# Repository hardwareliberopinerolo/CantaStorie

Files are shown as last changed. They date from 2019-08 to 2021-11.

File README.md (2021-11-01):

# Canta Storie realizzato con Arduino Mini Pro a 3.3V

Il Canta Storie riproduce brani MP3 (come le storie per i bambini) al passagio di Tag RFID

Le storie, in formato MP3, sono salvate su una SD Card e riprodotte dal lettore MP3 DFPlayer

I Tag RFID possono essere riciclati per esempio usando i biglietti usati dei mezzi pubblici che utilizzano questa tecnoligia

Arduino Mini Pro a 3.3V si occupa di gestire la lettura dei Tag RFID ed eseguire i brani MP3

Nella cartella [Arduino Sketches](/00_Arduino_Sketches) sono presenti gli Sketches da caricare su Arduino

Il Canta Storie è in grado di associare in modo automatico i Tag RFID ai brani MP3 che si vogliono riprodurre attraverso l'uso di un Tag RFID Master

**Materiale necessario**
- Arduino Mini Pro a 3.3V
- MP3 DFPlayer
- SD Card con file MP3
- Lettore RFID RC522
- Tessere/Tag RFID

Nella cartella [PCB Kicad](/01_PCB_Kicad) sono presenti gli schemi elettrici per costruire il circuito e il PCB

**Altre Versioni**

[Versione con Arduino Nano e RC522](/10_Other_Versions/Arduino_Nano_RC522): E' una versione che permette di usare Arduino Nano, in modo simile al progetto [TonUINO](https://github.com/seisfeld/TonUINO)

[Versione con Arduino Nano e PN532](/10_Other_Versions)

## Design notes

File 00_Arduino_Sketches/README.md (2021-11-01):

# Sketches

La cartella contiene lo [Sketch per Arduino Mini Pro a 3.3V](https://github.com/hardwareliberopinerolo/CantaStorie/tree/master/00_Arduino_Sketches/CantaStorie) del Canta Storie

Per semplificare la lettura del codice lo sketch è suddiviso in vari file ino in base alla funzionalità che eseguono

Ricordati di selezionare nel ArduinoIDE come Board: Arduino Mini Pro a 3.3V 

**Librerie Utilizzate**

[MP3 DF Player Mini](https://github.com/Makuna/DFMiniMp3)

[RC522 RFID Reader](https://github.com/miguelbalboa/rfid) 

[Ezprom](https://github.com/amirchev/EZPROM) 

**Comandi eseguibili dal Serial Monitor**

Premere nel serial monitor:

- R: Per resettare la memoria Eeprom e poi fare l'acquisizione carte
- L: per mostrare i codici RFID delle carte registrate
- M: per settare o Resettare la Master RFID card
- "+ / -" : Per aumentare o diminuire il volume
- D: per settare quanti brani random eseguire

## Esecuzione Brani Random
La nuova funzionalità di eseguire brani in modo random è stata aggiunta col lo Sketch [CS_Random](https://github.com/hardwareliberopinerolo/CantaStorie/tree/master/00_Arduino_Sketches/CS_Random_R03): Se si passa una RFID Card non programmata, viene eseguito un brano a caso
Con questa funzionalità è quindi possibile provare fin da subito il Canta Storie senza programmare le RFID Card

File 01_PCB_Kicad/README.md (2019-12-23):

# Schemi e PCB
La cartella contiene il progetto Kicad

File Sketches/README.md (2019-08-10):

**Arduino Sketches**

Questa cartella raccoglie gli sketch per Arduino del CantaStorie

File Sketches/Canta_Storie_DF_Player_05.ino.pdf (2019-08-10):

File: /mnt/6693a6f2-a89f-4d21-9a25-…/Canta_Storie_DF_Player_05.ino | Pagina 1 di 6

// this example will play a track and then
// every five seconds play another track
//
// it expects the sd card to contain these three mp3 files // but doesn't care whats in them
//
// sd:/mp3/0001.mp3
// sd:/mp3/0002.mp3
// sd:/mp3/0003.mp3

#include <SoftwareSerial.h>

#include <DFMiniMp3.h>

// https://github.com/Makuna/DFMiniMp3

#include <Wire.h>

#include <PN532_I2C.h>

#include <PN532.h>

#include <NfcAdapter.h>

PN532_I2C pn532i2c(Wire);
PN532 nfc(pn532i2c);

const uint8_t uid_ok1[] = { 0x4, 0xB1, 0x63, 0xDA, 0x31, 0x5B, 0x80 }; //UID SPT Subway 1 const uint8_t uid_ok2[] = { 0x4, 0x42, 0x55, 0x72, 0x62, 0x57, 0x80 }; //UID ciondolo viola const uint8_t uid_ok3[] = { 0xF6, 0x99, 0xBD, 0xAC,0,0,0 }; //UID ciondolo rosso
const uint8_t uid_ok4[] = { 0x4, 0x4D, 0x23, 0x2A, 0x52, 0x5D, 0x85 }; //UID GTT1
const uint8_t uid_ok5[] = { 0x4, 0x4B, 0x23, 0x2A, 0x52, 0x5D, 0x85 }; //UID GTT2
const uint8_t uid_ok6[] = { 0x4, 0x47, 0x3D, 0xDA, 0x64, 0x5D, 0x81 }; //UID GTT3
const uint8_t uid_ok7[] = { 0x5, 0x77, 0x7C, 0x6A, 0x99, 0x54, 0xE9 }; //UID GTT4
const uint8_t uid_ok8[] = { 0x5, 0x7D, 0x8C, 0xB9, 0x59, 0x54, 0xE9 }; //UID GTT5

const uint8_t uid_ok9[] = { 0x5, 0x76, 0x23, 0x1A, 0xE9, 0x54, 0xE9 }; //UID SPT Subway 2

const uint8_t uid_ok10[] = { 0x5, 0x7D, 0x62, 0x7B, 0x5A, 0x54, 0xE9 }; //UID SPT Subway 3

const uint8_t uid_ok11[] = { 0x5, 0x72, 0x8E, 0x19, 0x7A, 0x54, 0xE9 }; //UID SPT Subway 4

const uint8_t uid_ok12[] = { 0x5, 0x73, 0x7B, 0x9B, 0xE9, 0x54, 0xE9 }; //UID SPT Subway 5

int volume=15;

const int secondi=60;

// implement a notification class, // its member methods will get called //
class Mp3Notify
{
public:
static void OnError(uint16_t errorCode) {
// see DfMp3_Error for code meaning Serial.println();
Serial.print("Com Error "); Serial.println(errorCode);
}

static void OnPlayFinished(uint16_t globalTrack) {
Serial.println();
Serial.print("Play finished for #"); Serial.println(globalTrack);
}

static void OnCardOnline(uint16_t code) {
Serial.println();
Serial.print("Card online ");

File: /mnt/6693a6f2-a89f-4d21-9a25-…/Canta_Storie_DF_Player_05.ino | Pagina 2 di 6

Serial.println(code);
}

static void OnCardInserted(uint16_t code) {
Serial.println();
Serial.print("Card inserted "); Serial.println(code);
}

static void OnCardRemoved(uint16_t code) {
Serial.println();
Serial.print("Card removed "); Serial.println(code);
}
};

// instance a DFMiniMp3 object,
// defined with the above notification class and the hardware serial class
//
//DFMiniMp3<HardwareSerial, Mp3Notify> mp3(Serial1);

// Some arduino boards only have one hardware serial port, so a software serial port is needed instead. // comment out the above definition and uncomment these lines
SoftwareSerial secondarySerial(10, 11); // RX, TX
DFMiniMp3<SoftwareSerial, Mp3Notify> mp3(secondarySerial);

void setup()
{
Serial.begin(115200);

Serial.println("initializing...");

mp3.begin();

uint16_t volume = mp3.getVolume(); Serial.print("volume ");
Serial.println(volume);
mp3.setVolume(volume);

uint16_t count = mp3.getTotalTrackCount(); Serial.print("files ");
Serial.println(count);

Serial.println("starting...");

//PN532 Setup

nfc.begin();

uint32_t versiondata = nfc.getFirmwareVersion(); if (! versiondata) {
Serial.print("Didn't find PN53x board"); while (1); // halt
}
/*
// Got ok data, print it out!
Serial.print("Found chip PN5"); Serial.println((versiondata>>24) & 0xFF, HEX); Serial.print("Firmware ver. "); Serial.print((versiondata>>16) & 0xFF, DEC); Serial.print('.'); Serial.println((versiondata>>8) & 0xFF, DEC);
*/
// Set the max number of retry attempts to read from a card
// This prevents us from waiting forever for a card, which is // the default behaviour of the PN532. nfc.setPassiveActivationRetries(0xFF);

// configure board to read RFID tags
nfc.SAMConfig();

Serial.println("Waiting for an ISO14443A card");

File: /mnt/6693a6f2-a89f-4d21-9a25-…/Canta_Storie_DF_Player_05.ino | Pagina 3 di 6

}

void waitMilliseconds(uint16_t msWait) {
uint32_t start = millis();

while ((millis() - start) < msWait)
{
// calling mp3.loop() periodically allows for notifications // to be handled without interrupts
mp3.loop();
delay(1);
}
}

void loop()
{
int test=1;
boolean success;
uint8_t uid[] = { 0, 0, 0, 0, 0, 0, 0 }; // Buffer to store the returned UID
uint8_t uidLength; | // Length of the UID (4 or 7 bytes depending on ISO14443A
card type)

// Wait for an ISO14443A type cards (Mifare, etc.). When one is found
// 'uid' will be populated with the UID, and uidLength will indicate
// if the uid is 4 bytes (Mifare Classic) or 7 bytes (Mifare Ultralight) success = nfc.readPassiveTargetID(PN532_MIFARE_ISO14443A, &uid[0], &uidLength);

if (success) {
Serial.println("Found a card!");
//Serial.print("UID Length: ");Serial.print(uidLength, DEC);Serial.println(" bytes"); Serial.print("UID Value: ");
for (uint8_t i=0; i < uidLength; i++)
{
Serial.print(" 0x");Serial.print(uid[i], HEX); }
Serial.println("");
// Wait 1 second before continuing
// delay(1000);
if(uidLength==7){

test=memcmp(uid,uid_ok1,sizeof(uid)); if (test==0) {
Serial.println("Carta SPT Subway"); Serial.println("track 1"); mp3.playMp3FolderTrack(10);
delay(500);
mp3.playMp3FolderTrack(1); // sd:/mp3/0001.mp3 }

test=memcmp(uid,uid_ok4,sizeof(uid));
if (test==0) {
Serial.println("Carta GTT1"); Serial.println("track 2"); mp3.playMp3FolderTrack(10);
delay(500);
mp3.playMp3FolderTrack(2); // sd:/mp3/0001.mp3 }

test=memcmp(uid,uid_ok5,sizeof(uid));
if (test==0) {
Serial.println("Carta GTT2"); Serial.println("track 3"); mp3.playMp3FolderTrack(10);
delay(500);
mp3.playMp3FolderTrack(3); // sd:/mp3/0001.mp3 }

test=memcmp(uid,uid_ok6,sizeof(uid));
if (test==0) {
Serial.println("Carta GTT3");

File: /mnt/6693a6f2-a89f-4d21-9a25-…/Canta_Storie_DF_Player_05.ino | Pagina 4 di 6

Serial.println("track 3");
mp3.playMp3FolderTrack(10);
delay(500);
mp3.playMp3FolderTrack(6); // sd:/mp3/0001.mp3 }

//------------------------------------------------test=memcmp(uid,uid_ok7,sizeof(uid));
if (test==0) {
Serial.println("Carta GTT4"); Serial.println("track 3"); mp3.playMp3FolderTrack(10);
delay(500);
mp3.playMp3FolderTrack(5); // sd:/mp3/0001.mp3 }

//------------------------------------------------test=memcmp(uid,uid_ok9,sizeof(uid));
if (test==0) {
Serial.println("SPT Subway 2"); Serial.println("track 100"); mp3.playMp3FolderTrack(10);
delay(500);
mp3.playMp3FolderTrack(100); // sd:/mp3/0001.mp3 }
//------------------------------------------------test=memcmp(uid,uid_ok10,sizeof(uid));
if (test==0) {
Serial.println("SPT Subway 3"); Serial.println("track 101"); mp3.playMp3FolderTrack(10);
delay(500);
mp3.playMp3FolderTrack(101); // sd:/mp3/0001.mp3 }

//------------------------------------------------

test=memcmp(uid,uid_ok2,sizeof(uid));
if (test==0) {
Serial.println("Ciondolo Viola");

}

//------------------------------------------------test=memcmp(uid,uid_ok8,sizeof(uid));
if (test==0) {
Serial.println("Carta GTT4"); Serial.println("Stop");
mp3.playMp3FolderTrack(10); delay(500);
mp3.stop(); // stop
}
//------------------------------------------------

//------------------------------------------------test=memcmp(uid,uid_ok11,sizeof(uid));
if (test==0) {
Serial.println("SPT Subway 4");

if (volume<21){
Serial.println("volume+"); mp3.setVolume(++volume);}
}
//------------------------------------------------

//------------------------------------------------test=memcmp(uid,uid_ok12,sizeof(uid));
if (test==0) {
Serial.println("SPT Subway 5"); if (volume>9){

File: /mnt/6693a6f2-a89f-4d21-9a25-…/Canta_Storie_DF_Player_05.ino | Pagina 5 di 6

Serial.println("volume-");
mp3.setVolume(--volume);}
}
//------------------------------------------------

} //End Test uid_lenght 7

if(uidLength==4){

/*
test=memcmp(uid,uid_ok3,sizeof(uid)); if (test==0) {
Serial.println("Ciondolo Rosso"); Serial.println("track 4"); mp3.playMp3FolderTrack(4); // sd:/mp3/0002.mp3 }
*/

test=memcmp(uid,uid_ok3,sizeof(uid));
if (test==0) {
Serial.println("Ciondolo Rosso"); Serial.println("Stop");
mp3.stop(); // stop
}

} //End Test uid_lenght 7
Serial.println("");
}
else
{
// PN532 probably timed out waiting for a card // Serial.println("Timed out waiting for a card"); }
delay(1000);
mp3.loop(); //controlla il lettore per messaggi delay(1);

/*
Serial.println("track 1"); mp3.playMp3FolderTrack(1); // sd:/mp3/0001.mp3

waitMilliseconds(secondi*1000);

Serial.println("track 2"); mp3.playMp3FolderTrack(2); // sd:/mp3/0002.mp3

waitMilliseconds(secondi*1000);

mp3.setVolume(0);
waitMilliseconds(5*1000);
mp3.setVolume(15);

Serial.println("track 3"); mp3.playMp3FolderTrack(3); // sd:/mp3/0003.mp3

waitMilliseconds(5000);
*/
}

/* NOTE
https://github.com/Makuna/DFMiniMp3/blob/master/src/DFMiniMp3.h

DfMp3_Error
// from device
DfMp3_Error_Busy = 1,

File: /mnt/6693a6f2-a89f-4d21-9a25-…/Canta_Storie_DF_Player_05.ino | Pagina 6 di 6

DfMp3_Error_Sleeping,
DfMp3_Error_SerialWrongStack,
DfMp3_Error_CheckSumNotMatch,
DfMp3_Error_FileIndexOut,
DfMp3_Error_FileMismatch,
DfMp3_Error_Advertise,
// from library
DfMp3_Error_PacketSize = 0x81, DfMp3_Error_PacketHeader,
DfMp3_Error_PacketChecksum, DfMp3_Error_General = 0xff

*/

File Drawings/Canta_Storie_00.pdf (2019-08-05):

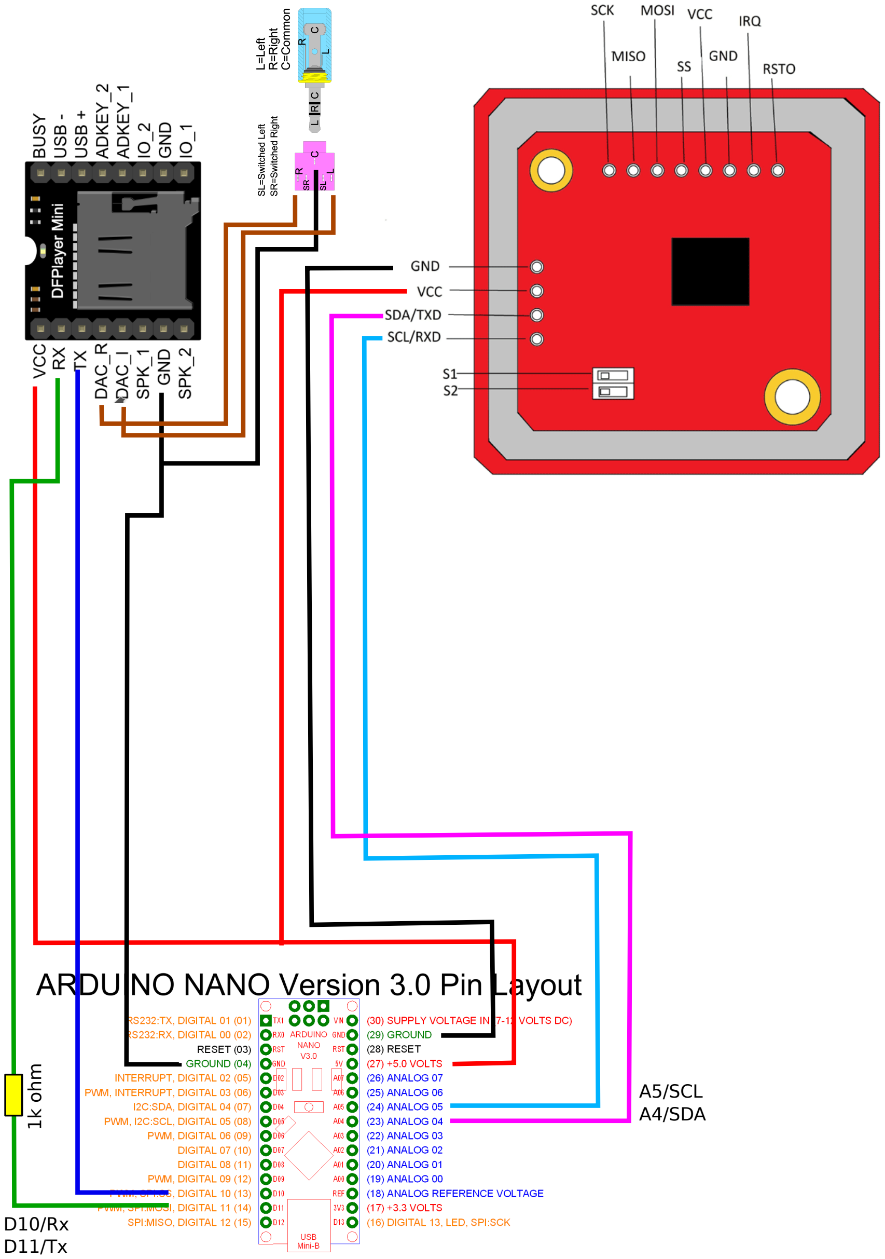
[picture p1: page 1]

1k ohm
A5/SCL
A4/SDA

D10/Rx
D11/Tx

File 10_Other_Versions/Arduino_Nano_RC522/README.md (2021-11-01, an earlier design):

# Canta Storie realizzato con Arduino Nano e RC522
La cartella contiene i file del Canta Storie realizzato con Arduino Nano e il sensore RFID RC522 che è meno costoso del PN532
Il funzionamento del Canta Storie è identico

**Materiale necessario**
- Arduino Nano a 5V
- MP3 DFPlayer
- SD Card con file MP3
- Lettore RFID RC522
- TXS0108E Level Shifter Breakout Board
- Tessere/Tag RFID

E' possibile usare il [Kit Tonuino di Az Delivery](https://www.az-delivery.de/it/products/tonuino-set) e acquistare a parte il TXS0108E

Lo Schema e il PCB del progetto è disponibile su EasyEDA [Canta Storie Arduino Nano - Schema e PCB](https://oshwlab.com/giorgio.boiero/tonuino-extended_copy)

Per precauzione è stato usato il TXS0108E Level Shifter perchè il lettore RFID RC522 non è garantito per funzionare con i 5V da NXP

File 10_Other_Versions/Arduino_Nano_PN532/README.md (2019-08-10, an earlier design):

# Canta Storie realizzato con Arduino Nano

Le storie, in formato MP3, sono salvate su una SD Card

I Tag RFID  possono essere riciclati per esempio usando quelli dei biglietti dei mezzi pubblici 

Nella cartella Drawings ci sono gli schemi elettrici per costruire il circuito
Nella cartella Sketches ci sono gli Sketches da caricare su Arduino

**Materiale necessario**
- Arduino Uno Nano
- MP3 DFPlayer
- SD Card con file MP3
- PN532
- Tessere/Tag RFID

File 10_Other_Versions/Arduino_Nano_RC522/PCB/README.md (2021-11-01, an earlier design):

# PCB Canta Storie con Arduino Nano e RC522

Il PCB del progetto è disponibile su EasyEDA [Canta Storie Arduino Nano PCB](https://oshwlab.com/giorgio.boiero/tonuino-extended_copy)

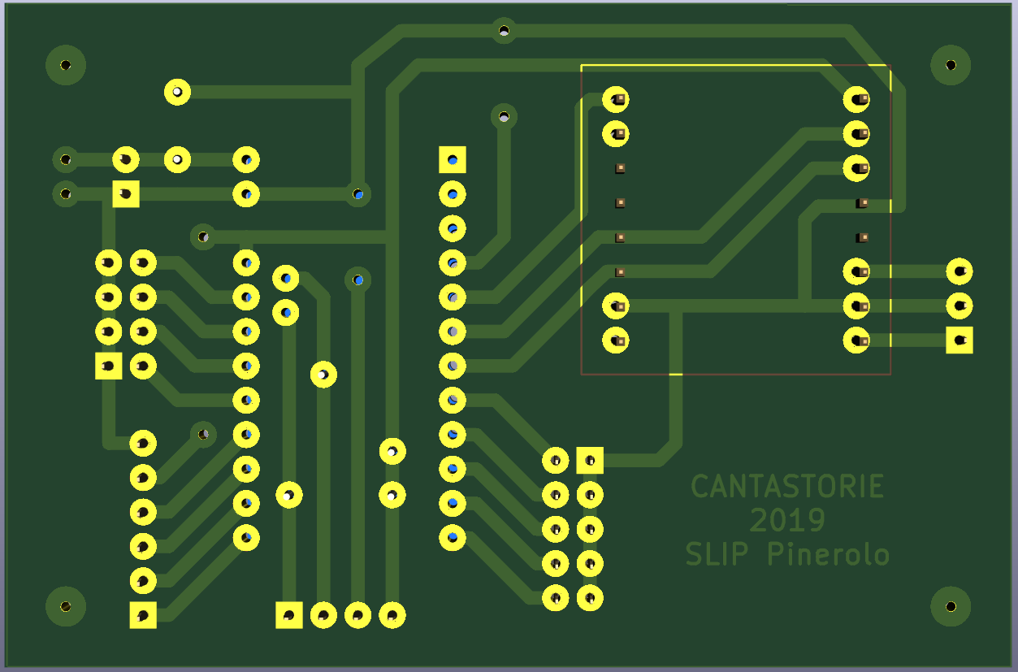
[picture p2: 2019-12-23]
01_PCB_Kicad/CantaStorie_Cu_Side.png

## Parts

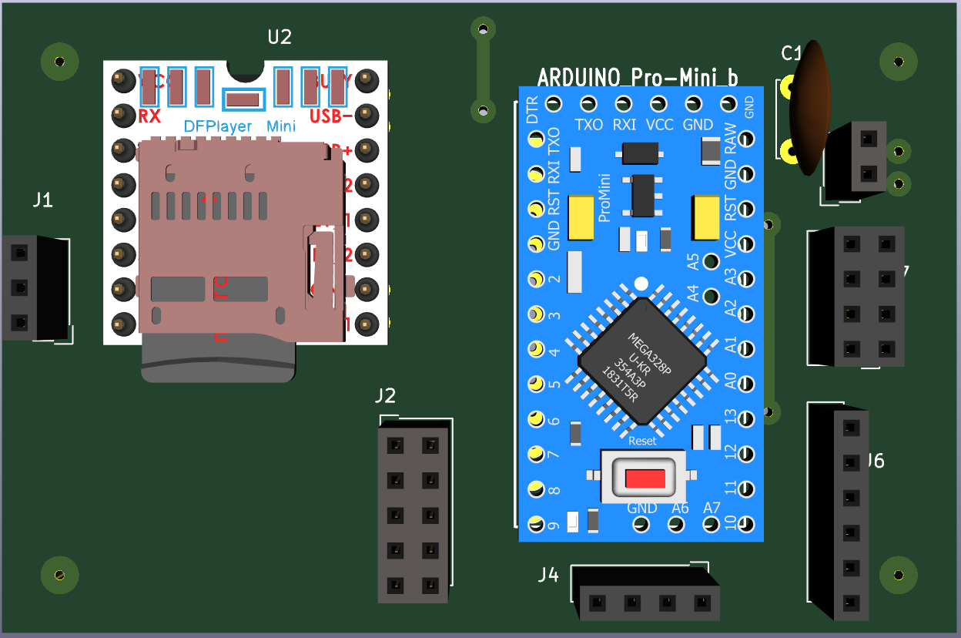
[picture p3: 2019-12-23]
01_PCB_Kicad/CantaStorie_Component_Side.png

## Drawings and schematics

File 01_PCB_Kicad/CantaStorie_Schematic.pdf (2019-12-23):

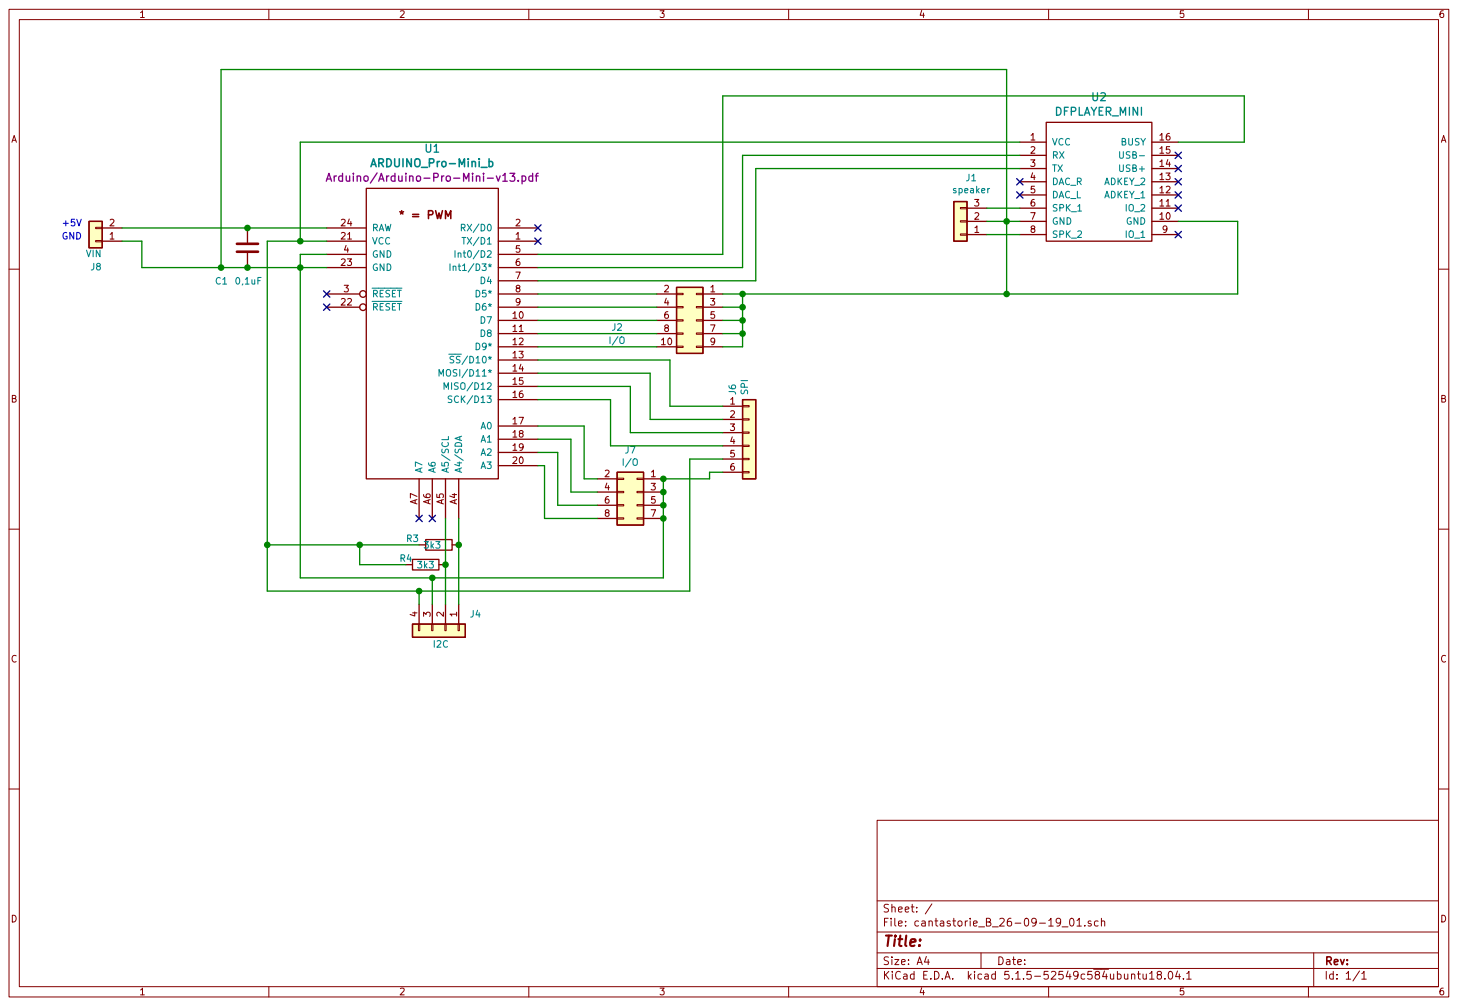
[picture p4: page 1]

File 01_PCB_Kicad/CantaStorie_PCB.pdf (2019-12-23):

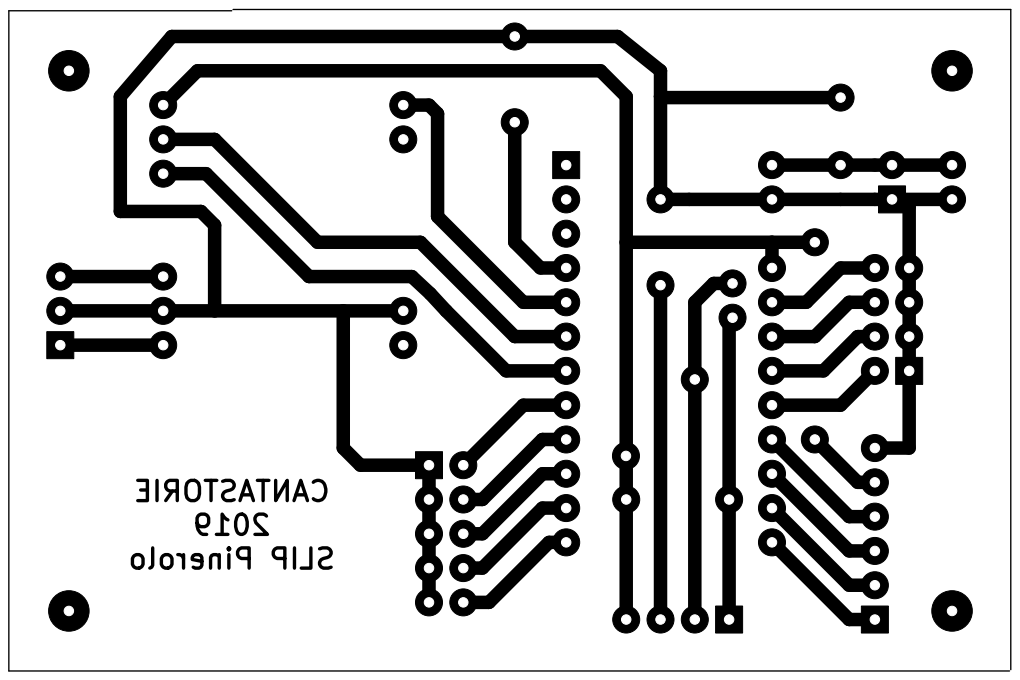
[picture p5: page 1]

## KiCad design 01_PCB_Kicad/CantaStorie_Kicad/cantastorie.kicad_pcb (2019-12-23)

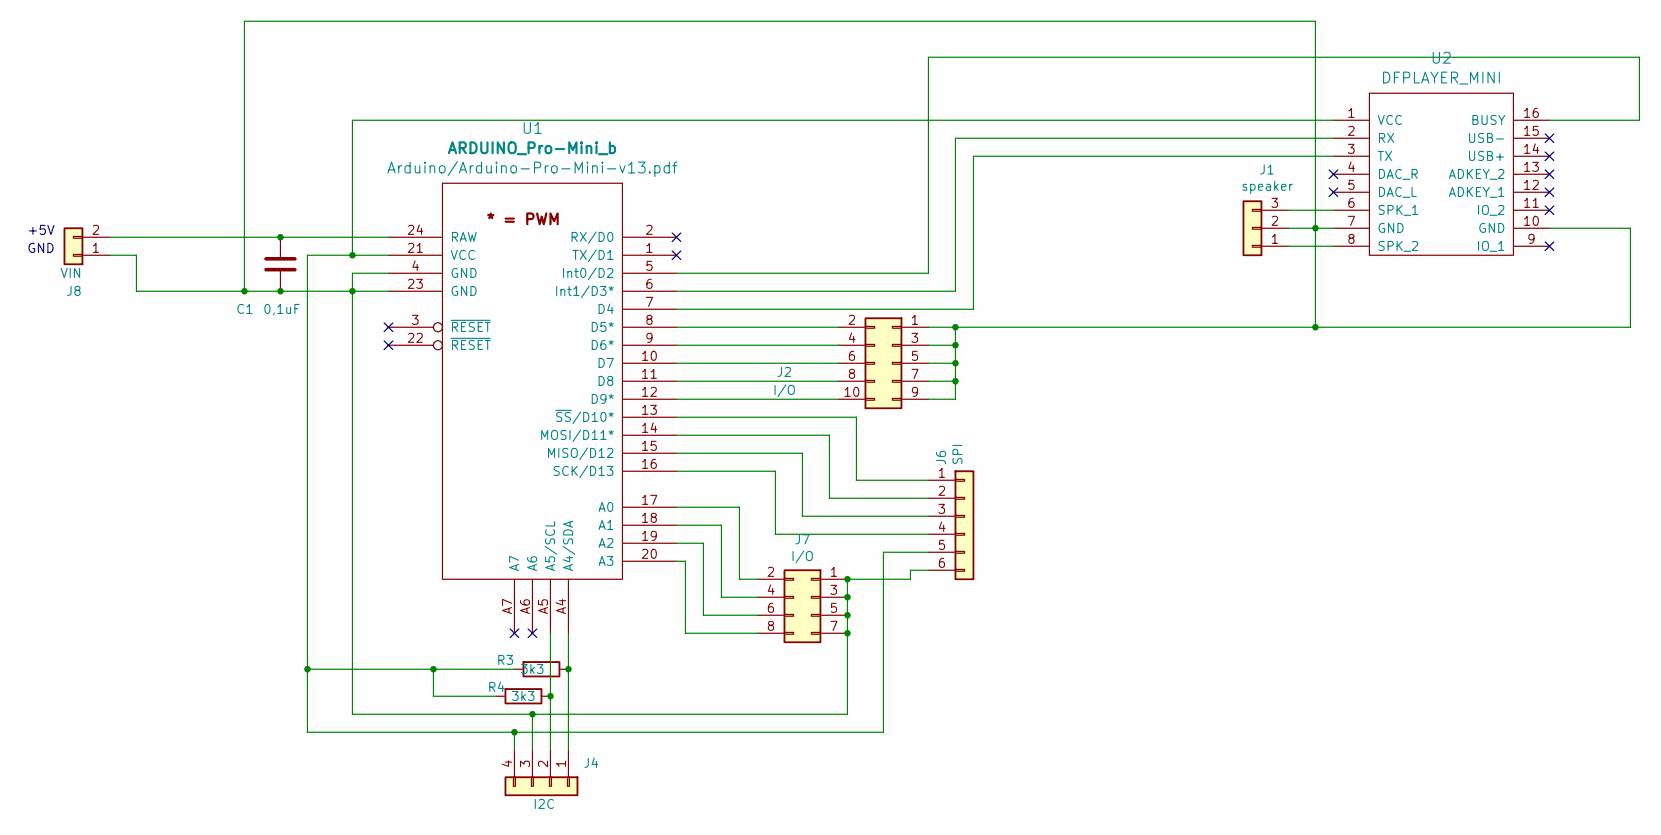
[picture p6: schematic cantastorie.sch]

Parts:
C1: 0,1uF; C_Disc_D6.0mm_W2.5mm_P5.00mm
J1: speaker; SL-103-X-XX_1x03
J2: I/O; SDL-110-X-XX_2x05
J4: I2C; SL-104-X-XX_1x04
J6: SPI; SL-106-X-XX_1x06
J7: I/O; SDL-108-X-XX_2x04
J8: VIN; SDL-102-X-XX_2x01
R3, R4: 3k3; R_Axial_DIN0204_L3.6mm_D1.6mm_P7.62mm_Horizontal
U1: ARDUINO_Pro-Mini_b; ARDUINO_Pro-MiniB_1
U2: DFPLAYER_MINI; DFPlayer_V3

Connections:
unnamed: C1.1, J8.2, U1.24 (RAW)
unnamed: C1.2, J1.2, J2.1, J2.3, J2.5, J2.7, J2.9, J4.3, J6.6, J7.1, J7.3, J7.5, J7.7, J8.1, U1.4 (GND), U1.23 (GND), U2.7 (GND), U2.10 (GND)
unnamed: J1.1, U2.8 (SPK_2)
unnamed: J1.3, U2.6 (SPK_1)
unnamed: J2.2, U1.8 (D5*)
unnamed: J2.4, U1.9 (D6*)
unnamed: J2.6, U1.10 (D7)
unnamed: J2.8, U1.11 (D8)
unnamed: J2.10, U1.12 (D9*)
unnamed: J4.1, R3.1, U1.A4 (A4/SDA)
unnamed: J4.2, R4.1, U1.A5 (A5/SCL)
unnamed: J4.4, J6.5, R3.2, R4.2, U1.21 (VCC), U2.1 (VCC)
unnamed: J6.1, U1.13 (~SS~/D10*)
unnamed: J6.2, U1.14 (MOSI/D11*)
unnamed: J6.3, U1.15 (MISO/D12)
unnamed: J6.4, U1.16 (SCK/D13)
unnamed: J7.2, U1.17 (A0)
unnamed: J7.4, U1.18 (A1)
unnamed: J7.6, U1.19 (A2)
unnamed: J7.8, U1.20 (A3)
unnamed: U1.5 (Int0/D2), U2.16 (BUSY)
unnamed: U1.6 (Int1/D3*), U2.2 (RX)
unnamed: U1.7 (D4), U2.3 (TX)

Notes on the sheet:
GND
+5V

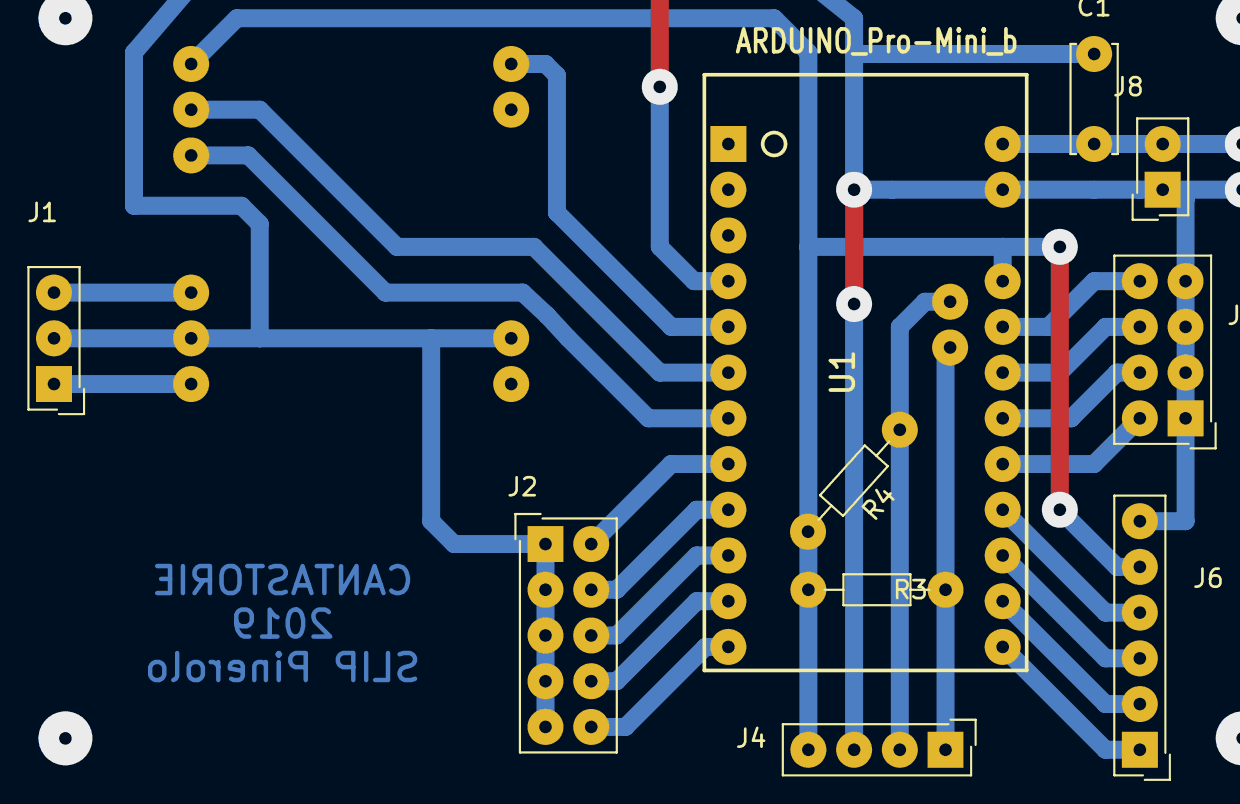
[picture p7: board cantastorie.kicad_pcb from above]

Board: 2 copper layers, 11 parts (0 on the bottom side), 23 nets.

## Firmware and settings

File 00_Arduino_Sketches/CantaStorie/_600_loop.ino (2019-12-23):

void loop(){
  if(Serial.available()){
    char inizializza=Serial.read();
    if(inizializza=='R'){ // Reset Eeprom
      initEEPROM();
      inizializza=' ';
    }
	else if(inizializza=='L'){ //Load cards from Eeprom
      read_eeprom();
      inizializza=' ';
    }
	else if(inizializza=='M'){ //Update Master card
      update_master();
      inizializza=' ';
    }
  }
  
	legge_rfid();
	delay(100); //1000
	mp3.loop(); //controlla il lettore per messaggi
	delay(10);
}

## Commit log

2019-12-23 Aggiornamento versione RC522
    [cantastorie.kicad_pcb, cantastorie.sch]
2021-11-01 Canta Storie con Arduino Nano
